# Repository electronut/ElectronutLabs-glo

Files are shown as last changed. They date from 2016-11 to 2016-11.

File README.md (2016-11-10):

# glo

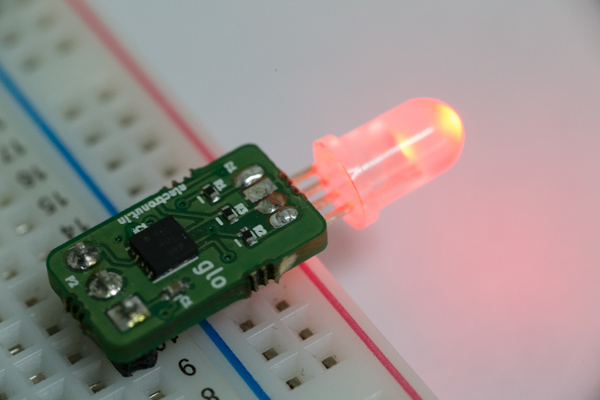
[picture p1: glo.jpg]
glo


glo is a tiny programmable RGB LED based on ATtiny13. The idea is that it can
be a "smart" drop-in replacement for a regular LED. For example, the LED could
flash in a pre-programmed way, or respond to analog input on the GPIO pin.

Specifications:

- Atmel ATtiny13 (10M1 package)
- Common cathode RGB LED
- 3 Pins - VCC, GND, GPIO
- Standard 2x3 ICSP header (pads) for programming
- Can be programmed using a Pogo Pin programmer or equivalent

glo on hackaday:

https://hackaday.io/project/18083-glo

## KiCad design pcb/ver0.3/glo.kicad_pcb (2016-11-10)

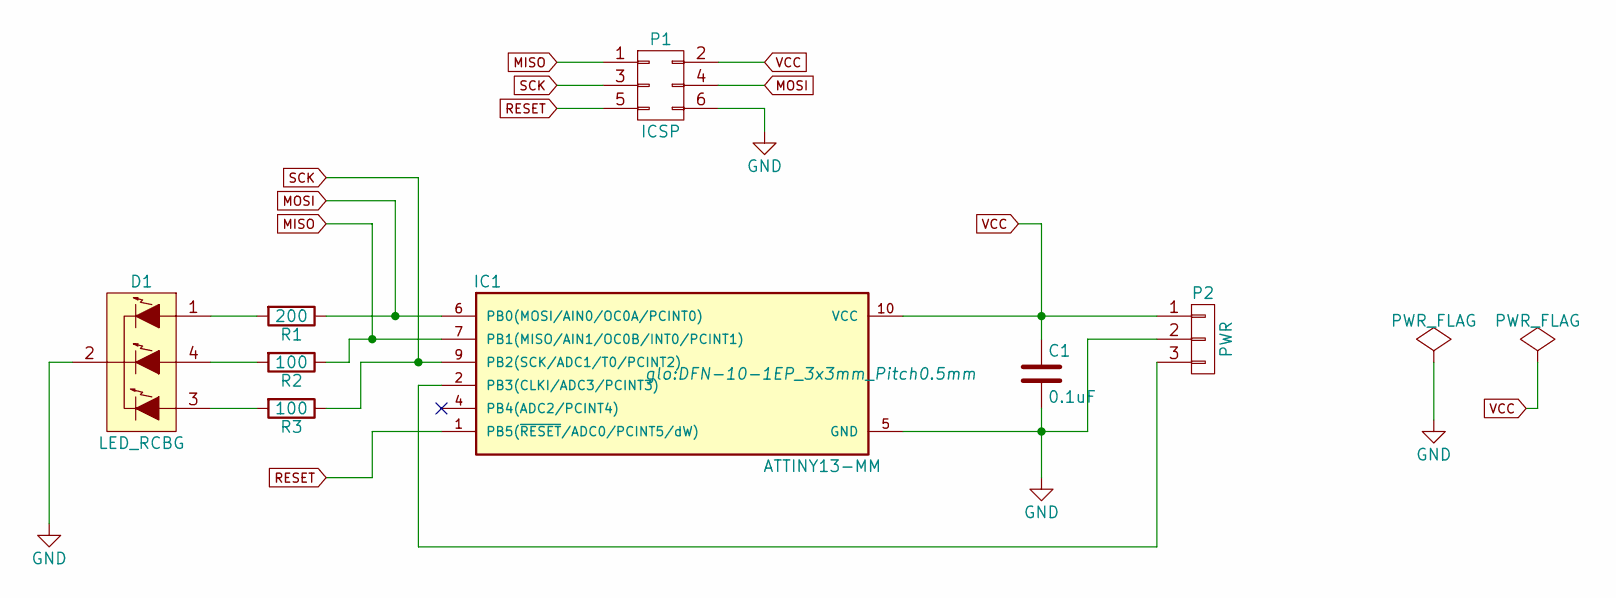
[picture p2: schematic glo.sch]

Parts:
C1: 0.1uF; C_0402
D1: LED_RCBG; LED-RGB-5MM_Common_Cathode
IC1: ATTINY13-MM; DFN-10-1EP_3x3mm_Pitch0.5mm
P1: ICSP; pogo_prog_2x3
P2: PWR; Pin_Header_Angled_1x03
R1: 200; R_0402
R2, R3: 100; R_0402

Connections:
GND: C1.2, D1.2 (COMMON_CATHODE), IC1.5 (GND), P1.6, P2.2
MISO: IC1.7 (PB1(MISO/AIN1/OC0B/INT0/PCINT1)), P1.1, R2.1
MOSI: IC1.6 (PB0(MOSI/AIN0/OC0A/PCINT0)), P1.4, R1.1
unnamed: D1.1 (RED_ANODE), R1.2
unnamed: D1.3 (BLUE_ANODE), R3.2
unnamed: D1.4 (GREEN_ANODE), R2.2
unnamed: IC1.2 (PB3(CLKI/ADC3/PCINT3)), P2.3
RESET: IC1.1 (PB5(~RESET~/ADC0/PCINT5/dW)), P1.5
SCK: IC1.9 (PB2(SCK/ADC1/T0/PCINT2)), P1.3, R3.1
VCC: C1.1, IC1.10 (VCC), P1.2, P2.1

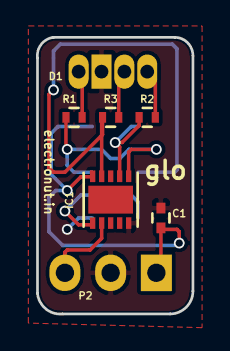
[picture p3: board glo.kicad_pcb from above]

Board: 2 copper layers, 8.6 x 15.4 mm, 8 parts (1 on the bottom side), 10 nets.

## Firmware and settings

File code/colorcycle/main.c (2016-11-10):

/*
 * attiny13-rgb-hello
 *
 * Drive an RGB LED using ATtiny13A.
 *
 * Author : electronut Labs
 * Website: electronut.in
 */


// define CPU speed
#define F_CPU 9600000UL

#include <avr/io.h>

#include<avr/pgmspace.h>
#include<avr/interrupt.h>

#include <util/delay.h>

int main (void)
{
	// set pin directions
	DDRB |= (1 << PB0) | (1 << PB1) | (1 << PB2);

  // loop
  while (1) {

    // set PB0 high
    PORTB = (1 << PB0);

    _delay_ms(200);

    // set PB0 low
    PORTB &= ~(1 << PB0);

    _delay_ms(200);

		// set PB1 high
    PORTB = (1 << PB1);

    _delay_ms(200);

    // set PB1 low
    PORTB &= ~(1 << PB1);

    _delay_ms(200);

		// set PB2 high
    PORTB = (1 << PB2);

    _delay_ms(200);

    // set PB2 low
    PORTB &= ~(1 << PB2);

    _delay_ms(200);
  }

  return 1;
}
